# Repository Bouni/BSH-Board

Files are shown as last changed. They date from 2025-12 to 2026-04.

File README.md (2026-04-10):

# BSH-Board

This project is one of many variants of a PCB that can be used to interface with B/S/H appliances using the awsome [bsh-home-appliances](https://github.com/hn/bsh-home-appliances) project.



# Warning
> [!WARNING]
> Household appliances work with high voltages and currents. They generate heat and steam, they shake, vibrate and have rotating parts. You should have a good knowledge of electrics and take appropriate safety measures before opening or modifying such an appliance. Parts can get wet or hot, move or fall off.

> [!WARNING]
> Even if parts of the appliances operate at low voltages, depending on your specific model they may or may not be isolated from earth. This is a good chance of death or serious injury.
> I'm not responsible if you kill your cat, your spouse, your favourite pet fish, or yourself, whichever of these is the worst for you. You have been warned.

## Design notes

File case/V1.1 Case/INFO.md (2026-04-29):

# 3D files for V1.1 Case

- This case works for V1.0 and V1.1 boards
- The 4 round holes are ment to be filled with a [magnet](https://www.supermagnete.de/scheibenmagnete-neodym/scheibenmagnet-5mm-5mm_S-05-05-N) each

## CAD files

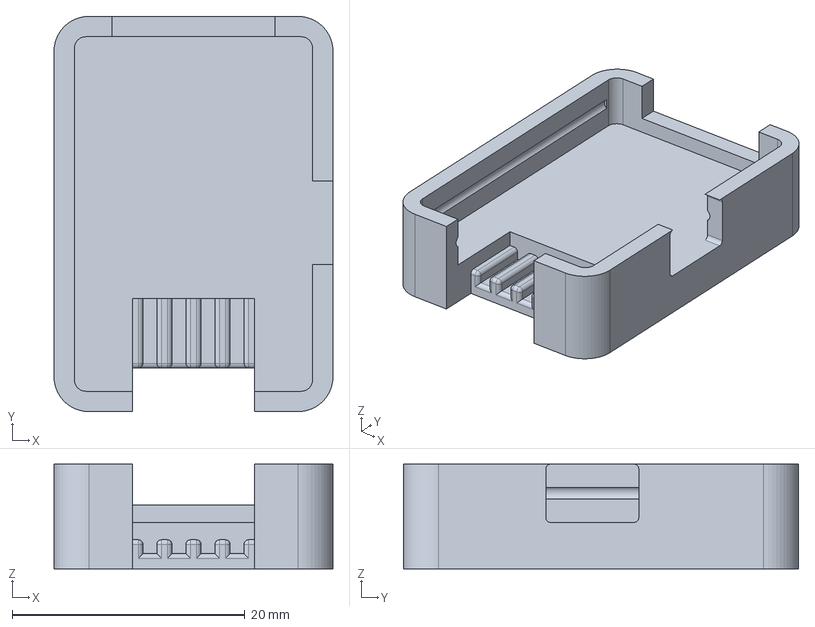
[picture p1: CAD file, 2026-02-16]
case/V1.0-RC2 Case/Base-V1.0-RC2.step
24.0 x 34.0 x 9.00 mm

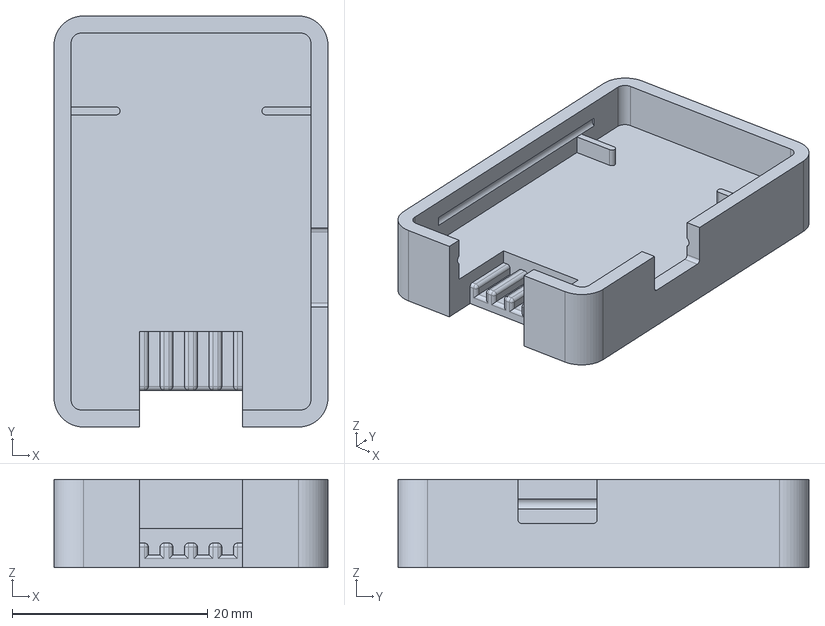
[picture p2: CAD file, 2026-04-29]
case/V1.1 Case/Base-V1.1.step
28.0 x 42.0 x 9.00 mm

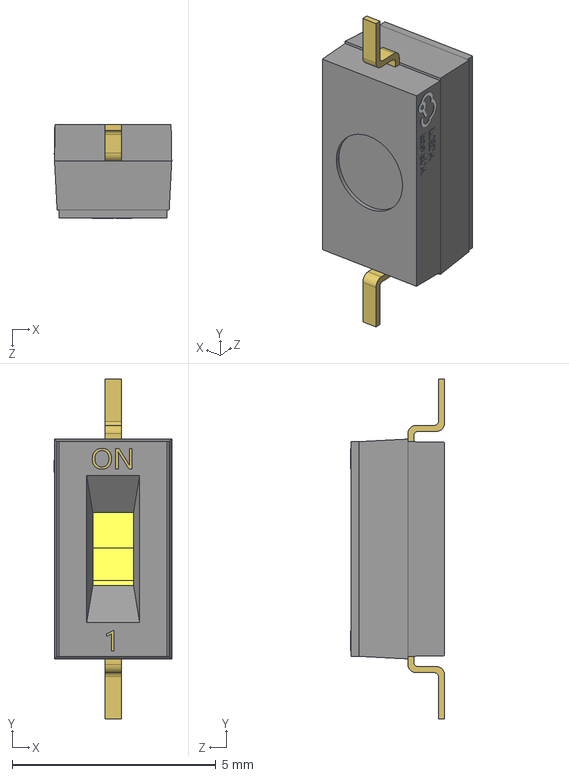
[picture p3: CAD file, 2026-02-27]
footprints/SW-SMD_DSHP01TSGER.step
2.89 x 8.35 x 2.31 mm

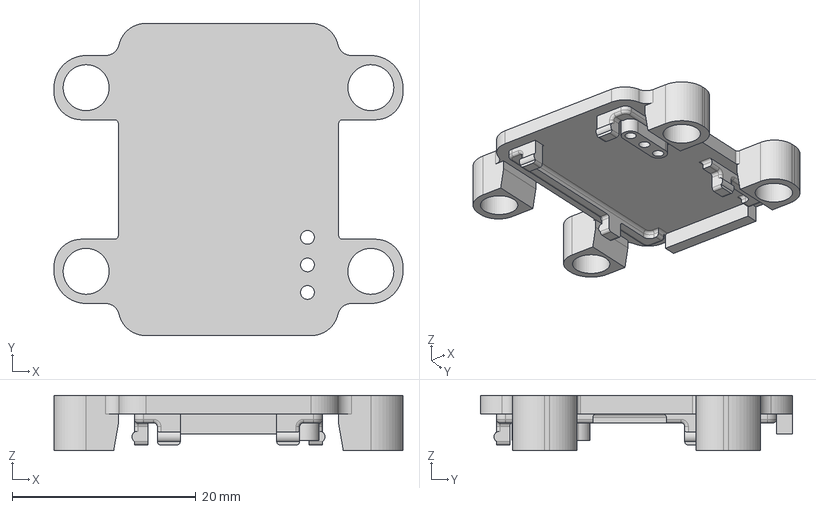
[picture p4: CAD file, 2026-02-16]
case/V1.0-RC2 Case/Lid-V1.0-RC2.step
38.0 x 34.0 x 6.00 mm

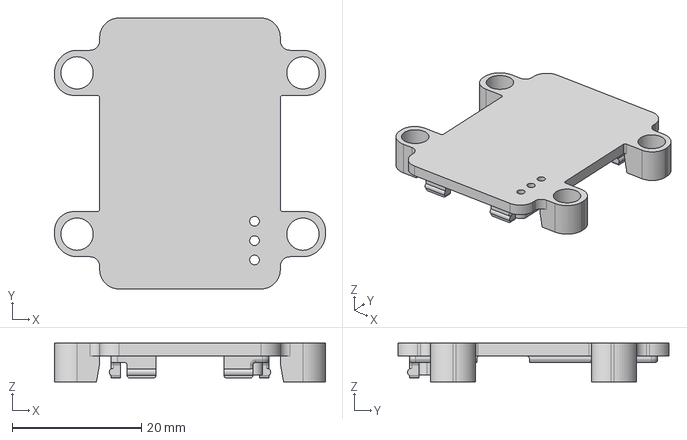
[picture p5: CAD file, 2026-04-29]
case/V1.1 Case/Lid-V1.1.step
42.0 x 42.0 x 6.00 mm

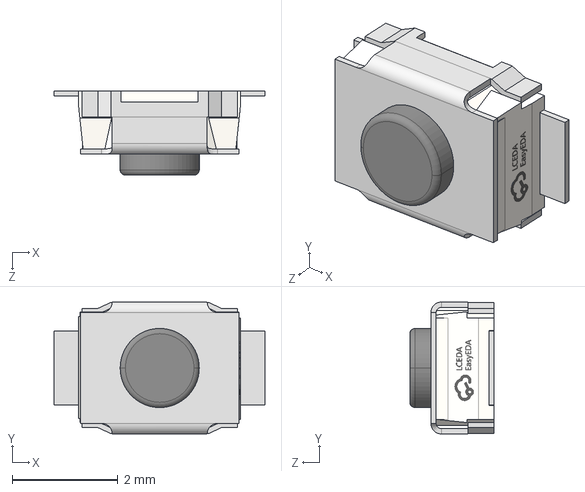
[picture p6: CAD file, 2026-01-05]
footprints/SW-SMD_L3.0-W2.5-P3.40-LS4.0-L.step
4.00 x 2.50 x 1.60 mm

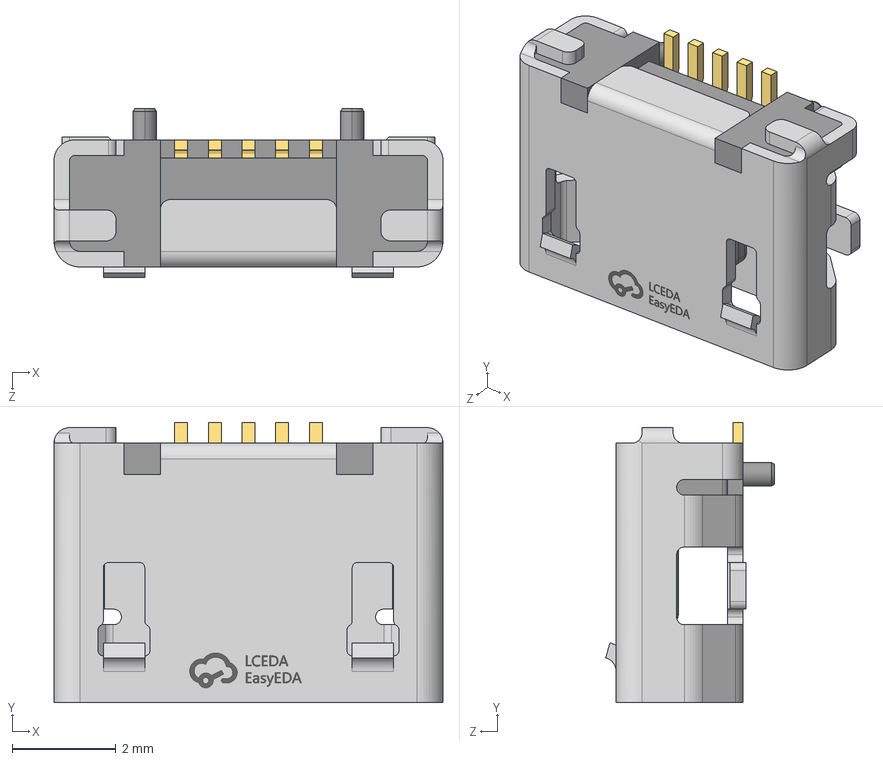
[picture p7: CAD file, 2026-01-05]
footprints/MICRO-USB-SMD_MICRO-QTZB5.0.step
7.50 x 5.40 x 3.25 mm

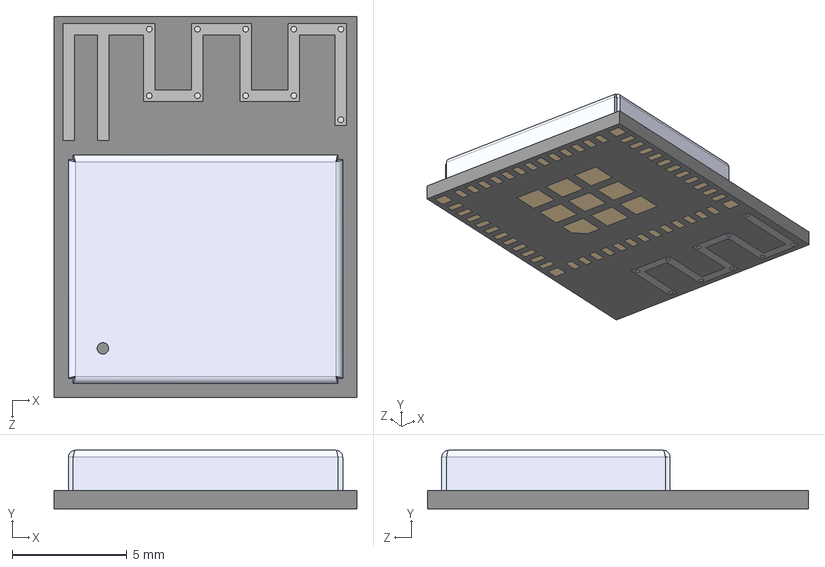
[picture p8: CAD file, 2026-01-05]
footprints/ESP32-C6-MINI-1-N4.step
13.2 x 2.55 x 16.6 mm

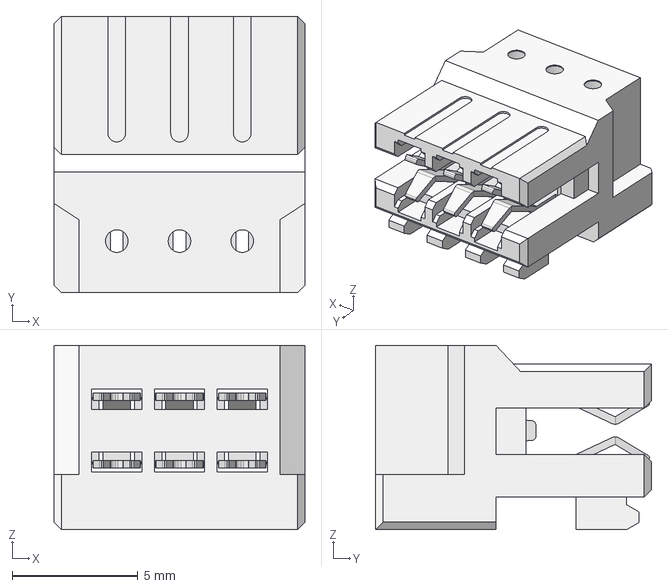
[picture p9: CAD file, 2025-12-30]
footprints/J_Wurth_WR-RAST_667101230103.step
10.0 x 11.0 x 7.35 mm

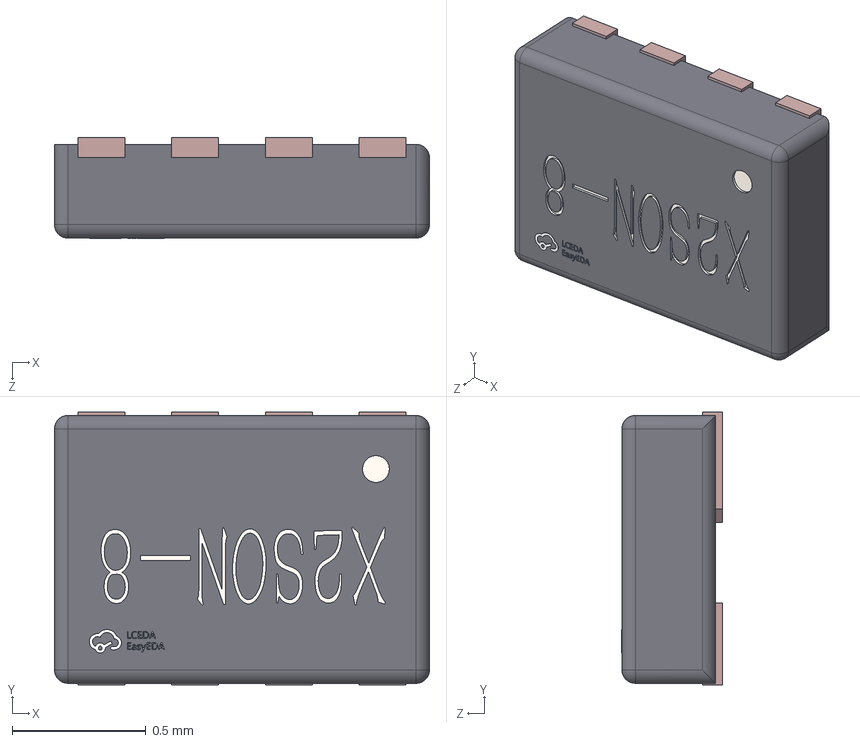
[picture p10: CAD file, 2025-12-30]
footprints/X2SON-8_L1.4-W1.0-P0.35-BL.step
1.40 x 1.02 x 0.376 mm

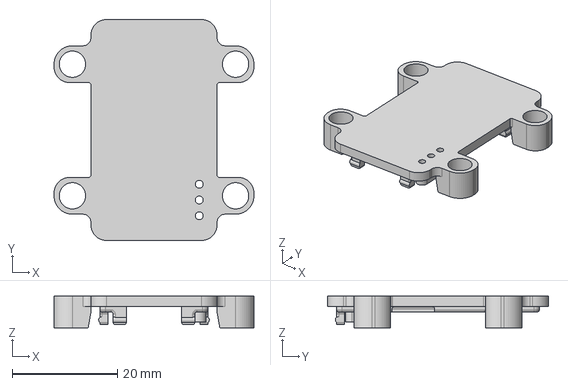
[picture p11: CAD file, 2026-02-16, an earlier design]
case/V1.0 Case/Lid-V1.0.step
38.0 x 42.0 x 6.00 mm

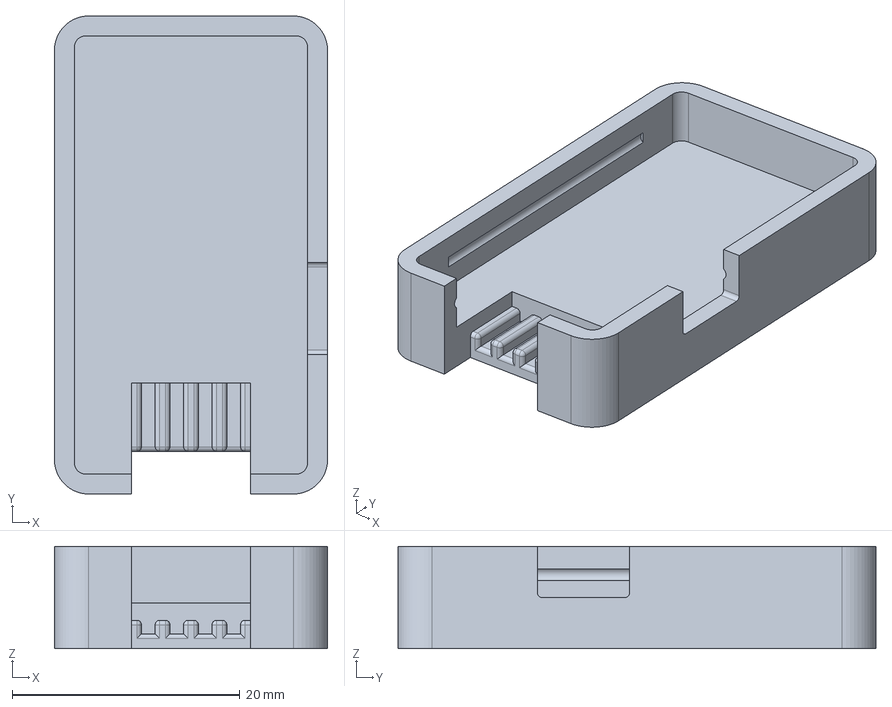
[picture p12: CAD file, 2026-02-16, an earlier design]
case/V1.0 Case/Base-V1.0.step
24.0 x 42.0 x 9.00 mm

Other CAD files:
case/V1.0-RC2 Case/Base.step
case/V1.0-RC2 Case/Lid.step

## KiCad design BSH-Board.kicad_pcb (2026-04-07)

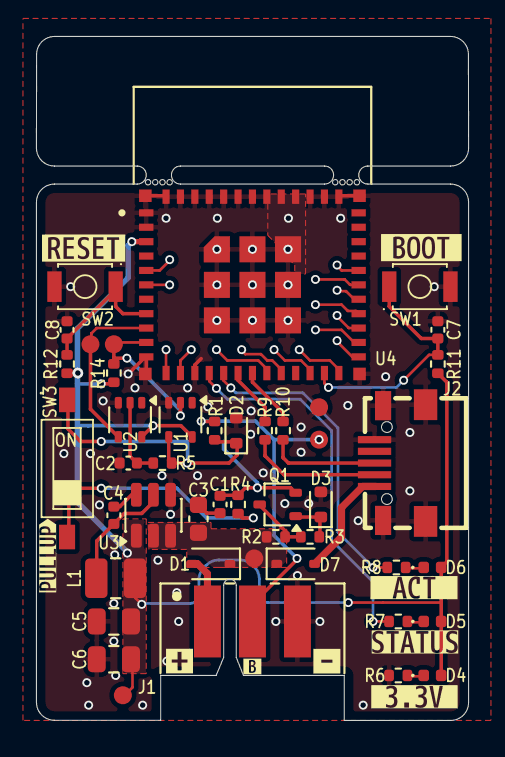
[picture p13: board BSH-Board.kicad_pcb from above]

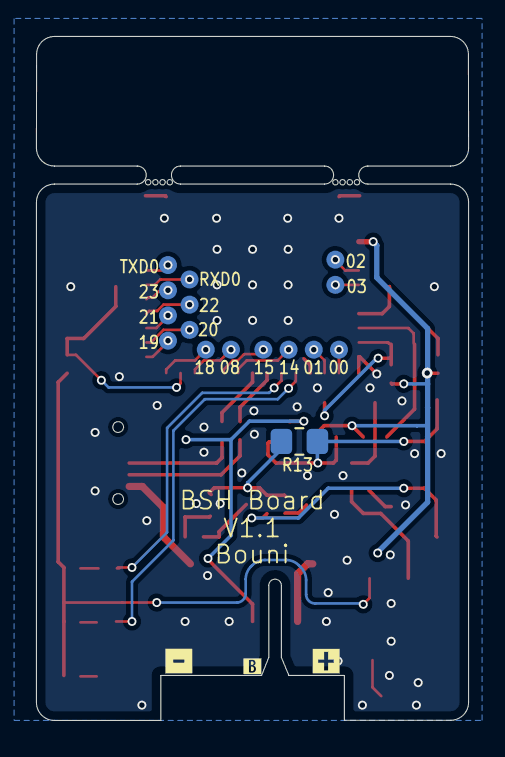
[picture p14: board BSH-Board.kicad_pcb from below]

Board: 2 copper layers, 24.0 x 38.0 mm, 73 parts (19 on the bottom side), 42 nets.

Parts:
C1, C4, C7, C8: 100nF; C_0402_1005Metric
C2: 1nF; C_0402_1005Metric
C3: 10uF; C_0603_1608Metric
C5, C6: 22uF; C_0805_2012Metric
D1, D7: 1N5819WS; D_SOD-323
D2, D3: BZX584C5V6; D_SOD-523
D4: LED_R; LED_0402_1005Metric
D5: LED_G; LED_0402_1005Metric
D6: LED_B; LED_0402_1005Metric
J1: 667101210103; J_Wurth_WR-RAST_667101230103
J2: MICRO QTZB5.0; MICRO-USB-SMD_MICRO-QTZB5.0
L1: 3.3uH; L_1008_2520Metric
Q1: MMST3904; SOT-323_SC-70
R1: 100; R_0402_1005Metric
R2, R5: 1K; R_0402_1005Metric
R3: 100K; R_0402_1005Metric
R4, R11, R12, R14: 10k; R_0402_1005Metric
R6, R7, R8: 510; R_0402_1005Metric
R9, R10: 22; R_0402_1005Metric
R13: ?k; R_0805_2012Metric_Pad1.20x1.40mm_HandSolder
SW1, SW2: TS-3025-B-C-B; SW-SMD_L3.0-W2.5-P3.40-LS4.0-L
SW3: SW_DIP_x01; SW-SMD_DSHP01TSGER
TP1, TP2, TP3, TP4, TP5, TP6, TP7, TP8, TP9, TP10, TP11, TP12, TP13, TP14, TP15, TP16, TP17, TP18, TP19, TP20, TP21: TestPoint; TestPoint_Pad_D1.0mm
U1: 74LVC1G07; SOT-353_SC-70-5
U2: 74LVC1G17; SOT-353_SC-70-5
U3: AP63203WU; TSOT-23-6
U4: ESP32-C6-MINI-1-N4; XCVR_ESP32-C6-MINI-1-N4
kibuzzard-69A53AD7: G***; kibuzzard-69A53AD7
kibuzzard-69A53AE7: G***; kibuzzard-69A53AE7
kibuzzard-69A53B6F: G***; kibuzzard-69A53B6F
kibuzzard-69A53B23: G***; kibuzzard-69A53B23
kibuzzard-69A53B53: G***; kibuzzard-69A53B53
kibuzzard-69A53BB2, kibuzzard-69A53BB2#2: G***; kibuzzard-69A53BB2
kibuzzard-69A53BC4, kibuzzard-69A53BC4#2: G***; kibuzzard-69A53BC4
kibuzzard-69A53BD0, kibuzzard-69A53BD0#2: G***; kibuzzard-69A53BD0
kibuzzard-69A53C55: G***; kibuzzard-69A53C55

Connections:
+3.3V: C5.1, C6.1, D4.2 (A), D5.2 (A), D6.2 (A), L1.2, R11.2, R12.2, R14.2, TP6.1, U1.5 (VCC), U2.5 (VCC), U3.1 (FB), U4.3 (3V3)
ACTIVITY: R8.1, U4.16 (IO7)
BOOT: C7.1, R11.1, SW1.1, U4.23 (IO9)
DBUS-RX: TP4.1, U2.4, U4.9 (IO4)
DBUS-TX: R14.1, TP3.1, U1.2, U4.10 (IO5)
GND: C1.1, C2.1, C3.2, C5.2, C6.2, C7.2, C8.2, D2.2 (A), D3.2 (A), J1.A3, J2.5 (GND), J2.6 (Shield), R6.1, SW1.2, SW2.2, TP1.1, U1.3 (GND), U2.3 (GND), U3.4 (GND), U4.1 (GND1), U4.2 (GND1), U4.11 (GND1), U4.14 (GND1), U4.36 (GND1), U4.37 (GND1), U4.38 (GND1), U4.39 (GND1), U4.40 (GND1), U4.41 (GND1), U4.42 (GND1), U4.43 (GND1), U4.44 (GND1), U4.45 (GND1), U4.46 (GND1), U4.47 (GND2), U4.48 (GND2), U4.49_1 (GND2), U4.49_2 (GND2), U4.49_3 (GND2), U4.49_4 (GND2), U4.49_5 (GND2), U4.49_6 (GND2), U4.49_7 (GND2), U4.49_8 (GND2), U4.49_9 (GND2), U4.50 (GND2), U4.51 (GND2), U4.52 (GND2), U4.53 (GND2)
unnamed: C2.2, R5.1, U2.2
unnamed: D1.2 (A), J1.A1
unnamed: D2.1 (K), R1.1, R5.2, R13.1, SW3.1, U1.4
unnamed: D3.1 (K), Q1.1 (B), R3.1
unnamed: D4.1 (K), R6.2
unnamed: D5.1 (K), R7.2
unnamed: D6.1 (K), R8.2
unnamed: D7.2 (A), J2.1 (VBUS)
unnamed: J1.A2, R1.2, TP2.1
unnamed: Q1.3 (C), R2.1, R3.2
unnamed: C1.2, Q1.2 (E), R4.2, R13.2
unnamed: R4.1, SW3.2
unnamed: C4.2, U3.6 (BST)
unnamed: C4.1, L1.1, U3.5 (SW)
unnamed: TP7.1, U4.12 (IO0)
unnamed: TP8.1, U4.13 (IO1)
unnamed: TP9.1, U4.5 (IO2)
unnamed: TP10.1, U4.6 (IO3)
unnamed: TP11.1, U4.22 (IO8)
unnamed: R9.1, U4.17 (IO12)
unnamed: R10.1, U4.18 (IO13)
unnamed: TP14.1, U4.19 (IO14)
unnamed: TP15.1, U4.20 (IO15)
unnamed: TP16.1, U4.24 (IO18)
unnamed: TP17.1, U4.25 (IO19)
unnamed: TP18.1, U4.26 (IO20)
unnamed: TP19.1, U4.27 (IO21)
unnamed: TP20.1, U4.28 (IO22)
unnamed: TP21.1, U4.29 (IO23)
unnamed: TP13.1, U4.30 (RXD0)
unnamed: TP12.1, U4.31 (TXD0)
RESET: C8.1, R12.1, SW2.1, U4.8 (EN)
STATUS: R7.1, U4.15 (IO6)
USB-D+: J2.3 (D+), R10.2
USB-D-: J2.2 (D-), R9.2
VCC: C3.1, D1.1 (K), D7.1 (K), R2.2, TP5.1, U3.2 (EN), U3.3 (IN)

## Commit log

2025-12-30 Quick and dirty draft
    [BSH-Board.kicad_pcb, BSH-Board.kicad_sch, IND-SMD_L2.5-W2.0-VLS252012CX-150M.step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]
2025-12-30 Add LDO for 5V
    [BSH-Board.kicad_pcb, BSH-Board.kicad_sch, X2SON-4_L1.0-W1.0-P0.65-TL-EP.step]
2026-01-05 Added USB, replaced various parts
    [BSH-Board.kicad_pcb, BSH-Board.kicad_sch, ESP32-C6-MINI-1-N4.step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]
2026-01-05 Added LCSC numbers, replaced parts with Basic parts, added LEDs
    [BSH-Board.kicad_pcb, BSH-Board.kicad_sch]
2026-01-06 Minor improvements
    [BSH-Board.kicad_pcb, BSH-Board.kicad_sch]
2026-01-06 Almost there
    [BSH-Board.kicad_pcb, BSH-Board.kicad_sch]
2026-01-06 Fingers crossed
2026-01-07 Next attempt
    [BSH-Board.kicad_pcb, BSH-Board.kicad_sch]
2026-01-07 Fixed some issues, added missing JLC part numbers
    [BSH-Board.kicad_pcb, BSH-Board.kicad_sch]
2026-01-07 More cleanup
    [BSH-Board.kicad_pcb]
2026-01-16 Fix TXS0102DQER bug
    [BSH-Board.kicad_pcb, BSH-Board.kicad_sch]
2026-01-16 Adjusted resistor values for green and blue led
    [BSH-Board.kicad_sch]
2026-01-20 TXS0102 OE directly to 3.3v, all spare IOs to Testpoints
    [BSH-Board.kicad_pcb, BSH-Board.kicad_sch]
2026-01-20 Removed bottom pads of RAST connector
    [BSH-Board.kicad_pcb]
2026-01-20 Replaced TXS0102 with Pullup + 74LVC1G07 + Zener
    [BSH-Board.kicad_pcb, BSH-Board.kicad_sch]
2026-01-21 Went back to LSF0102
    [BSH-Board.kicad_pcb, BSH-Board.kicad_sch]
2026-01-22 Using 74LVC Logic, get rid of LDO for 5V
    [BSH-Board.kicad_pcb, BSH-Board.kicad_sch]
2026-01-22 Finished layout
    [BSH-Board.kicad_pcb, BSH-Board.kicad_sch]
2026-02-06 Extended board to reach under the antenna
    [BSH-Board.kicad_pcb, BSH-Board.kicad_sch]
2026-02-16 V1.0 with antenna cutout
    [BSH-Board.kicad_pcb]
2026-02-16 Add 3D models for a case for V1.0-RC2
    [Base.step, Lid.step]
2026-02-16 Fixed issue with lid clamping
    [Base-V1.0-RC2.step, Lid-V1.0-RC2.step]
2026-02-16 Add modified case version for V1.0
    [Base-V1.0.step, Lid-V1.0.step]
2026-02-16 Add RAST coding notch
    [BSH-Board.kicad_pcb]
2026-02-27 Add dip switch for pullup, add TX pullup, add empty 0805 for potential other pullup value
    [BSH-Board.kicad_pcb, BSH-Board.kicad_sch, SW-SMD_DSHP01TSGER.step]
2026-03-02 Various minor improvements
    [BSH-Board.kicad_pcb, BSH-Board.kicad_sch]
2026-03-02 Put V-Cut into seperate layer
    [BSH-Board.kicad_pcb]
2026-03-02 Hopefully fixed output now
    [BSH-Board.kicad_pcb, BSH-Board.kicad_sch]
2026-03-18 Update bsh-dbus-wm14e3a0.yaml
    remove debug from uart
2026-03-20 Replaced V-Cuts with Mousebites
    [BSH-Board.kicad_pcb]
2026-04-07 Fix version
    [BSH-Board.kicad_pcb, BSH-Board.kicad_sch]
2026-04-07 Restore Kicad 9 Files as Kibot does not yet support Kicad 10
    [BSH-Board.kicad_pcb, BSH-Board.kicad_sch]
2026-04-07 Fix #3, Silkscreen on the bottom layer was wrong (+/-)
    [BSH-Board.kicad_pcb]
2026-04-21 Add Case and Lid for V1.1
    [Base-V1.1.step, Lid-V1.1.step]
2026-04-29 Add updated V1.1 Case files
    [Base-V1.1.step, Lid-V1.1.step]
2026-04-29 Add INFO.md to case files
